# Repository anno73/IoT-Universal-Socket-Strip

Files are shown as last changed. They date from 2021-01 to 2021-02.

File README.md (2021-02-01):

# This is work in progress ...

# IoT Universal Socket Strip

Ever wanted to have a customizable socket strip? Now you can... 
This project enhances an [Ehmann](https://www.ehmann-gmbh.de/en/) [Universal Socket Strip](https://www.ehmann-gmbh.de/en/produkte/steckdosensysteme/steckdosenleisten/) 
like the [8-fold strip 0200x00082301](https://www.ehmann-gmbh.de/wp-content/uploads/2017/01/0200x00082301_0200x00082303_0200x00082305-data-sheet.pdf)
with custom relay controller and dedicated switching PCBs for each of the sockets.

The controller PCB is ESP8266 based, ideal for integration into your home IoT installation via e.g. MQTT.

# ToDo

Write firmware

Design power/controller and relay board.

Hardware, Software, Controller PCB, Relay PCB, Supporting Documents

# Best Practice Tutorials

## Git
[Using .gitignore the Right Way](https://labs.consol.de/development/git/2017/02/22/gitignore.html)

https://www.xspdf.com/resolution/57309756.html

## KiCad
[Better manage KiCAD projects using Git](https://medium.com/inventhub/better-manage-kicad-projects-using-git-8d06e1310af8)

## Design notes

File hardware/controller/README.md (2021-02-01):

# Power and Controller Board

ESP8266 - ESP12-F

Split logic from PSU?

AC-DC converter 240V->24V
AC-DC converter 240V->5V
DC-DC 5V 3.3V

Common reset
Level Shifter for IIC

## IIC

### IIC Level shifter

Bidirectional [Level shifting techniques in I2C-bus design](https://www.nxp.com/docs/en/application-note/AN10441.pdf) for Fast-mode and Standard-mode busses

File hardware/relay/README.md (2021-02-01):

# Relay Module PCB

One module for each socket.

# Next board revision

As of (AN2519)[http://ww1.microchip.com/downloads/en/Appnotes/AN2519-AVR-Microcontroller-Hardware-Design-Considerations-00002519B.pdf]

Add pull up resistor to RESET-Vcc (>10k)

Add cap between RESET-GND (100nF) - only if not using DebugWIRE

? Add diode between RESET-Vcc

V Add resistor between RESET-External_RESET_header

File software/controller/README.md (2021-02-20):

# Controller Board Software

ESP8266

[PlatformIO](https://platformio.org)

[VS Code](https://code.visualstudio.com/)

[IotWebConf](https://github.com/prampec/IotWebConf)

[MQTT](https://github.com/256dpi/arduino-mqtt)

[ArduinoJSON](https://arduinojson.org/)

[I2C - Wire.h](https://github.com/esp8266/Arduino/tree/master/libraries/Wire)

NTP - ESP8266 native

PolledTimeout - ESP8266 native ([Example](https://github.com/esp8266/Arduino/blob/master/libraries/esp8266/examples/BlinkPolledTimeout/BlinkPolledTimeout.ino))

AJAX?

# Supporting Stuff

## Arduino related

## Arduino ESP8266 Core related

[ESP8266 Blink with polledTimeout by Daniel Salazar](https://github.com/esp8266/Arduino/blob/master/libraries/esp8266/examples/BlinkPolledTimeout/BlinkPolledTimeout.ino) instead of millis() workaround.

## Exception Stack Trace Decoder

https://github.com/me-no-dev/EspExceptionDecoder

## I2C 

### Wire library

I encountered persisting problems with reading data from relay board. What solved it in the end was to add Wire.setClockStretchLimit() after Wire.begin():
```
Wire.begin(PIN_SDA, PIN_SCL, 1);  // Init IIC with master address 1
Wire.setClock(100000);            // 100kHz clock speed
Wire.setClockStretchLimit(40000); // 40ms
```

### I2C Level shifter

?? Use I2C against 5V rail? ESP8266 is 5V tolerant.

As it seems, a 5V powered ATTiny85 does not recognize 3.3V levels on I2C. So a level shifter needs to be used to convert to 5V levels as used by the ATTiny.

[sparkfun - Bi-Directional Logic Level Converter Hookup Guide](https://learn.sparkfun.com/tutorials/bi-directional-logic-level-converter-hookup-guide/all)

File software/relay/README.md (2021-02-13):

# Relay Board Software 

[ATTiny85](https://www.microchip.com/wwwproducts/en/ATtiny85)

[PlatformIO](https://platformio.org)

[VS Code](https://code.visualstudio.com/)

[I2C TinyWireSIO](https://github.com/rambo/TinyWire)

[EEPROMWearLevel](https://github.com/PRosenb/EEPROMWearLevel)

[SendOnlySoftwareSerial](https://github.com/nickgammon/SendOnlySoftwareSerial)

[Streaming](https://github.com/janelia-arduino/Streaming)

[avr-libc Watchdog](https://www.nongnu.org/avr-libc/user-manual/group__avr__watchdog.html)

Does each device need to remember configuration or should it get updated by host on power up?

# ToDo

- [ ] Sleep when not active - how to wake up? Pin change interrupt? 
- [ ] Watchdog timer
- [ ] Find issue on get requests with interleaving messages / subsequent writes

# Supporting Stuff

## Digistump Digispark USB Dev

### Platformio tweaks

#### Switch the platform package

I have encountered some issues with the Digistump avr package. There is missing EEPROM.h library. To resolve this I copied the original library from the arduino avr package to .platformio/packages/framework-avr-digistump/libraries package.
There is also a lot of unnecessary noise during compilation because of moved header file locations, redefinition of #define BIN and other stuff.
In addition EEPROMWearLevel library did not compile. 
This was the final reason for me to try a different core package.
In the end I overwrote core and variant from [Digispark USB](https://docs.platformio.org/en/latest/boards/atmelavr/digispark-tiny.html#board-atmelavr-digispark-tiny) package to tiny and tinyx5 as it is used by the [generic ATTiny85](https://docs.platformio.org/en/latest/boards/atmelavr/attiny85.html#board-atmelavr-attiny85) definitions (see [attiny85.json](https://github.com/platformio/platform-atmelavr/blob/master/boards/attiny85.json)). Keeping the rest as it is, allowed me to program regularly via USB. See [platformio.ini](platformio.ini).

There is a new actively maintained ATTiny85 core available on https://github.com/ArminJo/DigistumpArduino which gives smaller code, has active development, and more stock libraries. I use this now for further development.

#### Include (missing) libs as submodules

As I did not find [SendOnlySoftwareSerial](https://github.com/nickgammon/SendOnlySoftwareSerial) and a current version of [Streaming](https://github.com/janelia-arduino/Streaming) in PlatformIO's library repository, I added these as [git submodules](https://git-scm.com/book/en/v2/Git-Tools-Submodules) in the library folder.
See [github blog](https://github.blog/) for more information on [how to work with submodules](https://github.blog/2016-02-01-working-with-submodules/).
Especially on initial cloning you might need to use `git clone --recursive <project url>`. If you already have cloned the repository and only miss the submodules, `git submodule update --init --recursive` should do the trick.

### Windows Driver Installation

https://github.com/micronucleus/micronucleus/tree/master/windows_driver_installer

Use [zadig](https://zadig.akeo.ie/).

### Initial Flashing

[Connecting and Programming Your Digispark](http://digistump.com/wiki/digispark/tutorials/connecting)

### Flash digiStump Digispark USB dev board

[Digispark USB Development Board](http://digistump.com/products/1) Webshop listing

[Schematic](https://s3.amazonaws.com/digistump-resources/files/97a1bb28_DigisparkSchematic.pdf)

[Micronucleus](https://github.com/micronucleus/micronucleus) Bootloader

## C/C++

[Enumeration declaration](https://en.cppreference.com/w/cpp/language/enum)

## Arduino related

[Arduino Tutorial: Using millis[] Instead of delay[]](https://www.norwegiancreations.com/2017/09/arduino-tutorial-using-millis-instead-of-delay/)

[Arduino Tutorial: Avoiding the Overflow Issue When Using millis[] and micros[]](https://www.norwegiancreations.com/2018/10/arduino-tutorial-avoiding-the-overflow-issue-when-using-millis-and-micros/)

## I2C Resources

[I2C [Inter-Integrated Circuit] Bus Technical Overview and Frequently Asked Questions](https://www.esacademy.com/en/library/technical-articles-and-documents/miscellaneous/i2c-bus.html)

[Nick Gammon - I2C - Two-Wire Peripheral Interface - for Arduino](http://www.gammon.com.au/forum/?id=10896)

https://www.i2c-bus.org/

## Fuse Calc and Fuse Reset

[Engbedded Atmel AVR® Fuse Calculator](https://www.engbedded.com/fusecalc/)

https://www.elektronik-labor.de/Arduino/Fuses.html

TinyCalibrator from below

https://arduinodiy.wordpress.com/2015/05/16/high-voltage-programmingunbricking-for-attiny/

[Simple and Cheap Fuse Doctor for Attiny](https://www.instructables.com/Simple-and-cheap-Fuse-Doctor-for-Attiny/)

## Flash ATTiny85

### High Voltage Programming

[Nick Gammon - High-voltage programming for AVR chips](http://www.gammon.com.au/forum/?id=12898)

https://github.com/ArminJo/ATtiny-HighVoltageProgrammer_FuseEraser

### Flash ATTiny85

Arduino as a programmer

### Boot loader

[ATtiny85 I2C Bootloader](https://github.com/casanovg/timonel) to flash via ESP8266.
https://www.youtube.com/watch?v=-7GOMToGvzI

[Micronucleus](https://github.com/micronucleus/micronucleus) V-USB based.

## Debugging

### Serial TX only

https://github.com/nickgammon/SendOnlySoftwareSerial

### debugWire

* https://sites.google.com/site/wayneholder/debugwire
* https://www.youtube.com/watch?v=kI_Z78a_0y0

### IIC

[SoftI2CMaster](https://github.com/felias-fogg/SoftI2CMaster) provides [I2CShell](https://github.com/felias-fogg/SoftI2CMaster/tree/master/examples/I2CShell) as an example, which is a nice I2C command sending tool for Arduino.

## Calibrate RC Oscillator

* http://ww1.microchip.com/downloads/en/appnotes/atmel-2555-internal-rc-oscillator-calibration-for-tinyavr-and-megaavr-devices_applicationnote_avr053.pdf
* https://hackaday.com/2020/12/30/improve-attiny-timing-accuracy-with-this-clock-calibrator/
* https://hackaday.io/project/176542-tiny-calibrator
* https://github.com/wagiminator/ATtiny84-TinyCalibrator

## Power saving mode

[ATTiny85 Data sheet](https://ww1.microchip.com/downloads/en/DeviceDoc/Atmel-2586-AVR-8-bit-Microcontroller-ATtiny25-ATtiny45-ATtiny85_Datasheet.pdf) chapters
* 7 Power Management and Sleep Modes
* Table 7-1 Active Clock Domains and Wake-up Sources in the Different Sleep Modes
* 15.3.4 Two-wire Mode
* 15.3.5 Start Condition Detector
* 15.5.3 Bit 7 USISIF describes conditions for IIC Start condition waking up the CPU from sleep states.

Minimal power consumption is not required to not interfere with peripherals like LED and relay triggering outputs.

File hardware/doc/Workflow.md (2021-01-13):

# Used tools
* python
* freerouter
* KiKit

# Draw schematic in KiCad
# Create PCB
## Draw outlines
## Import components from schematic
## Place components
## Export Specctra DSN
 
# Autoroute
 
## Start Tools_Freerouter.cmd

# Reimport SES file to KiCad

# Panelize/Render/Document KiKit
## Setup Makefile

KiKit [panelization options explained](https://github.com/yaqwsx/KiKit/blob/master/doc/examples.md).

## Start Tools_KiKit.cmd (one off) or Tools_KiKit_Shell.cmd (repeat)

# To Do

* Export schematic to PDF
* Export PCB to PDF
* Export PCB to PNG

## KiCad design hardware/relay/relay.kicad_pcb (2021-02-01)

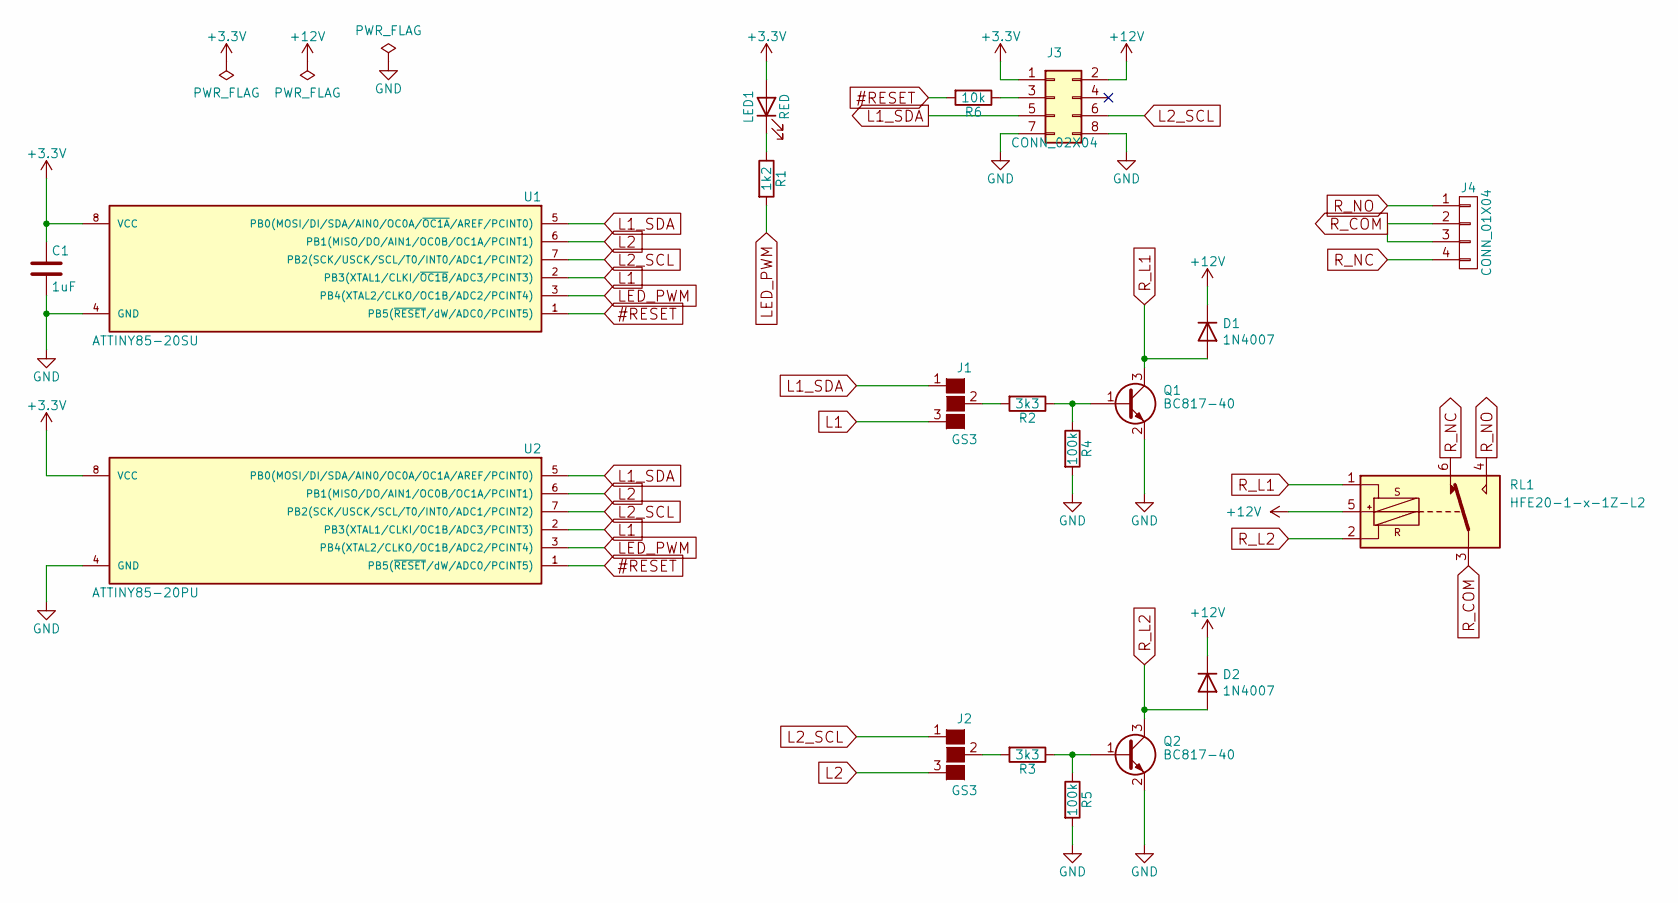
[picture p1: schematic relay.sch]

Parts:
C1: 1uF; C_0805_HandSoldering
D1, D2: 1N4007; D_SMA_Handsoldering
J1, J2: GS3
J3: CONN_02X04; Pin_Header_Straight_2x04_Pitch2.54mm
J4: CONN_01X04; SR21504VBNC
LED1: RED; LED_0805_HandSoldering
Q1, Q2: BC817-40; SOT-23_Handsoldering
R1: 1k2; R_0805_HandSoldering
R2, R3: 3k3; R_0805_HandSoldering
R4, R5: 100k; R_0805_HandSoldering
R6: 10k; R_0805_HandSoldering
RL1: HFE20-1-x-1Z-L2; HFE20-1_DPST_Double_Coil_Bistable
U1: ATTINY85-20SU; SOIC-8_3.9x4.9mm_Pitch1.27mm
U2: ATTINY85-20PU; DIP-8_W7.62mm_Socket

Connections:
#RESET: R6.2, U1.1 (PB5(~RESET~/dW/ADC0/PCINT5)), U2.1 (PB5(~RESET~/dW/ADC0/PCINT5))
+3V3: C1.1, J3.1, LED1.2 (A), U1.8 (VCC), U2.8 (VCC)
+12V: D1.1 (K), D2.1 (K), J3.2, RL1.5
GND: C1.2, J3.7, J3.8, Q1.2 (E), Q2.2 (E), R4.2, R5.2, U1.4 (GND), U2.4 (GND)
L1: J1.3 (G3), U1.2 (PB3(XTAL1/CLKI/~OC1B~/ADC3/PCINT3)), U2.2 (PB3(XTAL1/CLKI/OC1B/ADC3/PCINT3))
L1_SDA: J1.1 (G1), J3.5, U1.5 (PB0(MOSI/DI/SDA/AIN0/OC0A/~OC1A~/AREF/P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), U2.5 (PB0(MOSI/DI/SDA/AIN0/OC0A/OC1A/AREF/PCI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)
L2: J2.3 (G3), U1.6 (PB1(MISO/DO/AIN1/OC0B/OC1A/PCINT1)), U2.6 (PB1(MISO/DO/AIN1/OC0B/OC1A/PCINT1))
L2_SCL: J2.1 (G1), J3.6, U1.7 (PB2(SCK/USCK/SCL/T0/INT0/ADC1/PCINT2)), U2.7 (PB2(SCK/USCK/SCL/T0/INT0/ADC1/PCINT2))
LED_PWM: R1.2, U1.3 (PB4(XTAL2/CLKO/OC1B/ADC2/PCINT4)), U2.3 (PB4(XTAL2/CLKO/OC1B/ADC2/PCINT4))
unnamed: J1.2 (G2), R2.2
unnamed: J2.2 (G2), R3.2
unnamed: J3.3, R6.1
unnamed: LED1.1 (K), R1.1
unnamed: Q1.1 (B), R2.1, R4.1
unnamed: Q2.1 (B), R3.1, R5.1
R_COM: J4.2, J4.3, RL1.3
R_L1: D1.2 (A), Q1.3 (C), RL1.1
R_L2: D2.2 (A), Q2.3 (C), RL1.2
R_NC: J4.4, RL1.6
R_NO: J4.1, RL1.4

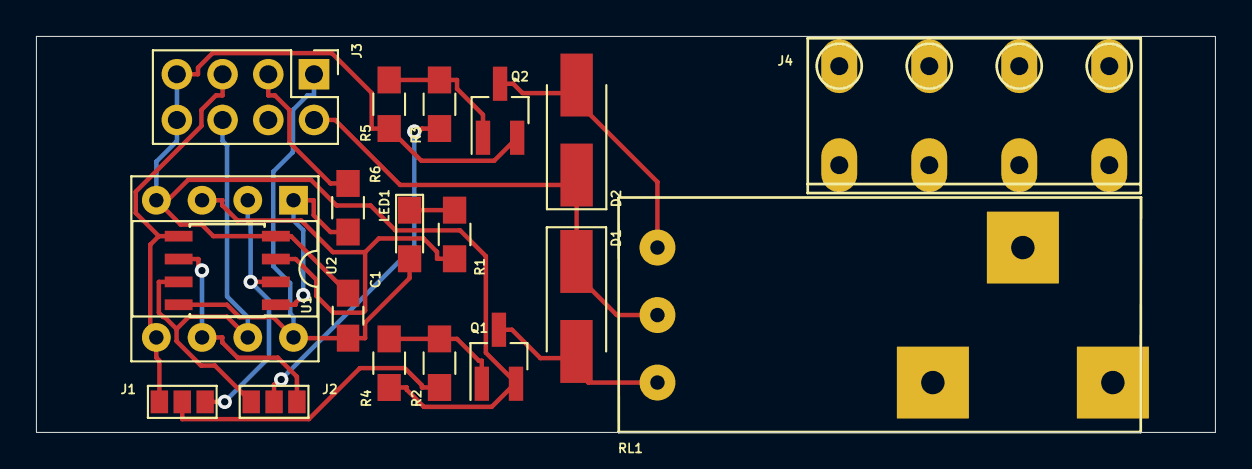
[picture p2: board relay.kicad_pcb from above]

Board: 2 copper layers, 65.5 x 22.0 mm, 19 parts (0 on the bottom side), 20 nets.

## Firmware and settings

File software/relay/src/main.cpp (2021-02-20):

#include <Arduino.h>

// #include <avr/sleep.h>
// #include <avr/power.h>

#include "shared.h"

#define DEBUG_IIC_IO
#define DEBUG_CMD
#define DEBUG_CONFIG
// #define DEBUG_EEPROM

#ifdef DEBUG_EEPROM
#define DEBUG_CORE
#define dbg_eep(x) txOnlySerial << x
#else
#define dbg_eep(x)
#endif

#ifdef DEBUG_IIC_IO
#define DEBUG_CORE
#define dbg_iic_io(x) txOnlySerial << x
#else
#define dbg_iic_io(x)
#endif

#ifdef DEBUG_CMD
#define DEBUG_CORE
#define dbg_cmd(x) txOnlySerial << x
#else
#define dbg_cmd(x)
#endif

#ifdef DEBUG_CONFIG
#define DEBUG_CORE
#define dbg_cfg(x) txOnlySerial << x
#else
#define dbg_cfg(x)
#endif

#ifdef DEBUG_CORE
#warning DEBUG enabled on target. SoftwareSerial output on LED pin.
const unsigned long txOnlySerialBaudRate = 115200;
#include <SendOnlySoftwareSerial.h> // https://github.com/nickgammon/SendOnlySoftwareSerial
#include <Streaming.h>              // https://github.com/janelia-arduino/Streaming
// #define dbg(x) txOnlySerial << x
#define dbg_core(x) txOnlySerial << x
#else
// #define dbg(x)
#define dbg_core(x)
#endif

#include "EEPROM.h"
#include <EEPROMWearLevel.h> // https://github.com/PRosenb/EEPROMWearLevel

// const byte EWL_LAYOUT_VERSION = 1;
#define EWL_LAYOUT_VERSION 1
// const int EWL_USE_BYTES = 500;
#define EWL_USE_BYTES 500

const int EWLIDX_STATUS = 0;
const int EWLIDX_RELAY = 1;
const int EWLIDX_LED = 2;
// const int EWLIDX_BUTTON = 3;
// const int EWLIDX_COUNT = 3;
#define EWLIDX_COUNT 3

const unsigned int EEPIDX_IICADDR = 511; // Absolute EEPROM index

#include <TinyWireS.h> // https://github.com/nickcengel/TinyWireSio
#ifndef TWI_RX_BUFFER_SIZE
#define TWI_RX_BUFFER_SIZE (16)
#endif

#define CIRCULAR_BUFFER_INT_SAFE
#include <CircularBuffer.h> // https://github.com/rlogiacco/CircularBuffer

CircularBuffer<uint8_t, TWI_RX_BUFFER_SIZE> cmdBuf; // Command buffer for processing IIC commands in main loop.

#include <avr/wdt.h> // avr-libc watchdog library https://www.nongnu.org/avr-libc/user-manual/group__avr__watchdog.html <Watchdog.h> does not support ATTiny85

/**
 * Forward Declarations
 */
void initIic(uint8_t);
void iicRequestEventCb(void);
void iicReceiveEventCb(uint8_t);
void dumpEEPROM(void);

/**
 * ATTiny85 Pin Usage
 * 
 * ATTiny   Port  Arduino   Function
 * Pin #    Pin   Pin # 
 *   1      PB5    5/A0     /RESET
 *   2      PB3    3/A3
 *   3      PB4    4/A2
 *   4      -       -       GND
 *   5      PB0     0       IIC SDA
 *   6      PB1     1
 *   7      PB2    2/A1     IIC SCL
 *   8              -       VCC
 */

const uint8_t PIN_SCL = 0;
const uint8_t PIN_SDA = 2;

const uint8_t PIN_RL1 = 1;
const uint8_t PIN_RL2 = 3;

const uint8_t PIN_LED = 4;
const uint8_t PIN_BUTTON = 5;

const uint32_t IIC_BITRATE = 100000;
volatile uint8_t iicSlaveAddress = 127; // "Factory" default address for automated recognition of new modules and initialisation by controller
// volatile uint8_t iicSlaveAddress = 125; // Test address during dev
uint8_t softwareVersion = 0;

// const uint8_t RELAY_SWITCH_PULSE_DURATION_MS = 15;
const uint8_t RELAY_SWITCH_PULSE_DURATION_MS = 50;
// const uint8_t RELAY_COIL_OFF = LOW;
// const uint8_t RELAY_COIL_ON = HIGH;
const uint8_t RELAY_COIL_OFF = HIGH;
const uint8_t RELAY_COIL_ON = LOW;

const uint8_t LED_ON = LOW;
const uint8_t LED_OFF = HIGH;

#ifdef DEBUG_CORE
SendOnlySoftwareSerial txOnlySerial(PIN_LED); // Reuse LED pin for software serial.
#endif

/*
  Operations !!! BEWARE OF FEATURE CREEP !!! Maybe creep a bit for education and fun.

  Button is totally optional due to mechanical reasons of base hardware.

  Relay operation
    Set relay state ON/OFF
    Get relay state
    Set freeze relay state lock/unlock 
    Get freeze relay state
  Set LED operational mode
    0: Follow relay (default)
    1: -
    2: Independent fixed state
      0: off
      1: on
    4: Independent blink
      3..0: rate
  Get LED status
  Get LED operational mode
  Set button operation
    0: Toggle relay
    1: off
    2: notify I2C master
  Get button status
  Set IIC Address
  Get IIC Address
  Get Software Version
*/

/**
 * 
 * ??? have array or dedicated variables to hold I2C register values
 * ??? we could have "virtual" registers not needing a storage space because they trigger some action upon r/w.
 *
 * Usage would probably be like this then:
 * typedef struct { uint8_t a, b, c; } reg_struct; 
 * union iicReg_u { uint8_t r[6] ; reg_struct s; }
 * iicReg_u iicRegs;
 * iicReg.r[0] = 0;
 * iicReg.s.a = 0;
 * 
 */

// Make this a union of array and struct
// volatile uint8_t iicRegs[] = {
//     0x00, // 0: Status Register
//     0x00, // 1: Set relay state
//     0x00, // 2: IIC Address Register
//     0x00  // 3: Software version
// };

// For now be conservative and define each possible register on its own. Select access via switch/case instead of array index.

/**
 * statusReg
 * 
 * 76543210
 * 
 * 0: relay status
 *      0: off
 *      1: on
 * 2: led status
 *      0: off
 *      1: on
 * 7: busy - cannot accept command
 *      0: false - commands accepted
 *      1: true - commands accepted but discarded
 */
volatile uint8_t statusReg = 0;
const uint8_t STATUS_BIT_RELAY = 0;
const uint8_t STATUS_BIT_LED = 2;
const uint8_t STATUS_BIT_BUSY = 7;

/**
 * relayReg
 * 
 * 76543210
 * 
 * 0:   on/off
 *      0: relay off
 *      1: relay on
 * 1:   freeze/unfreeze
 *      0: unfreeze
 *      1: freeze
 */
volatile uint8_t relayReg = 0;
const uint8_t RELAY_BIT_ONOFF = 0;
const uint8_t RELAY_BIT_FREEZE = 1;

/**
 * ledReg
 * 
 * 76543210
 * 
 * 0: on/off
 *      0: off
 *      1: on
 * 1:   follow relay
 *      0: follow relay
 *      1: switch separately
 * 2:   freeze/unfreeze
 *      0: unfreeze
 *      1: freeze
 * 3:
 * 54:  blink rate
 *      00
 *      01
 *      10
 *      11
 */
volatile uint8_t ledReg = 0;
const uint8_t LED_BIT_ONOFF = 0;
const uint8_t LED_BIT_FOLLOW = 1;
const uint8_t LED_BIT_FREEZE = 2;

/**
 * buttonReg
 * 
 * 76543210
 * 
 * 0: on/off    Read only
 *      0: off
 *      1: on
 * 1: enable/disable
 *      0: enabled
 *      1: disabled
 * 2: freeze/unfreeze
 *      0: unfreeze
 *      1: freeze
 */
volatile uint8_t buttonReg = 0;
// volatile uint8_t addrReg = 0;    // does not need to be a physical register. Is obtained from EEPROM.
// volatile uint8_t versionReg = 0; // does not need to be a physical register. Is a constant in the code.

volatile uint8_t iicRegSelectedRead = 0;          // For read operations persist the selected register across IIC operations
const uint8_t iicRegSize = iicRegister::REGCOUNT; // How many registers we have defined
const uint8_t iicRegLastIdx = iicRegSize - 1;     // Index of the last register for wrap around on multiple read/write operations
                                                  //
volatile bool persistIicRegs = false;             // If true, persist register values in main loop

/**
 * ledAction
 * 
 * Execute actions/configs on LED
 *  ON/OFF/TOGGLE/...
 * 
 */
void ledAction(uint8_t action)
{

    // dbg_core(F("ledAction: ") << action << endl);
    dbg_core(millis() << F(" ledAction: ") << action << endl);

    if (bitRead(ledReg, LED_BIT_FOLLOW) == 0)
    { // LED in follow relay mode. Only some actions allowed:
        switch (action)
        {
        case ledCmd::UNFOLLOW_RELAY: // intentionally fallthrough all allowed commands.
        case ledCmd::FOLLOW_RELAY:
        case ledCmd::FREEZE:
        case ledCmd::UNFREEZE:
        case ledCmd::RELAY_OFF:
        case ledCmd::RELAY_ON:
            break;
        default:
            return;
        }
    }

    if (bitRead(ledReg, LED_BIT_FREEZE) == 1)
    { // LED in freeze mode. Only some actions allowed:
        switch (action)
        {
        case ledCmd::RELAY_OFF: // intentionally fallthrough all allowed commands.
        case ledCmd::RELAY_ON:
        case ledCmd::FREEZE:
        case ledCmd::UNFREEZE:
            break;
        default:
            return;
        }
    }

    persistIicRegs = true;

    switch (action)
    {
    case ledCmd::RELAY_OFF:
        bitClear(ledReg, LED_BIT_ONOFF);
        bitClear(statusReg, STATUS_BIT_LED);

#ifndef DEBUG_CORE
        // In debug mode PIN_LED gets serial output
        digitalWrite(PIN_LED, LED_OFF);
#endif
        break;
    case ledCmd::RELAY_ON:
        bitSet(ledReg, LED_BIT_ONOFF);
        bitSet(statusReg, STATUS_BIT_LED);

#ifndef DEBUG_CORE
        // In debug mode PIN_LED gets serial output
        digitalWrite(PIN_LED, LED_ON);
#endif
        break;
    case ledCmd::UNFOLLOW_RELAY:
        bitClear(ledReg, LED_BIT_FOLLOW);
        break;
    case ledCmd::FOLLOW_RELAY:
        bitSet(ledReg, LED_BIT_FOLLOW);

        // Initialize LED with current relay state
        if (bitRead(relayReg, RELAY_BIT_ONOFF) == 0)
        {
            ledAction(ledCmd::RELAY_OFF);
        }
        else
        {
            ledAction(ledCmd::RELAY_ON);
        }
        break;
    case ledCmd::OFF:
        bitClear(ledReg, LED_BIT_ONOFF);
        bitClear(statusReg, STATUS_BIT_LED);

#ifndef DEBUG_CORE
        // In debug mode PIN_LED gets serial output
        digitalWrite(PIN_LED, LED_OFF);
#endif
        break;
    case ledCmd::ON:
        bitSet(ledReg, LED_BIT_ONOFF);
        bitSet(statusReg, STATUS_BIT_LED);

#ifndef DEBUG_CORE
        // In debug mode PIN_LED gets serial output
        digitalWrite(PIN_LED, LED_ON);
#endif
        break;
    case ledCmd::TOGGLE:
        if (bitRead(ledReg, LED_BIT_ONOFF) == 0)
        {
            ledAction(ledCmd::ON);
        }
        else
        {
            ledAction(ledCmd::OFF);
        }
        break;
    case ledCmd::UNFREEZE:
        bitClear(ledReg, LED_BIT_FREEZE);
        break;
    case ledCmd::FREEZE:
        bitSet(ledReg, LED_BIT_FREEZE);
        break;
    default:
        // Unknown or unimplemented command
        persistIicRegs = false;
        break;
    }

    return;
} // ledAction

/**
 * relayAction
 * 
 * Initial idea:
 * Execute operations that take longer than allowed in the IIC callback routine.
 * This is mainly the relay switching, as it requires some delay on the coil to properly switch.
 * 
 * Now:
 * Encapsulate relay operation
 */
void relayAction(uint8_t action)
{

    // dbg_core(F("relayAction: ") << action << endl);
    dbg_core(millis() << F(" relayAction: ") << action << endl);

    // If relay is in freeze state then only action allowed is unfreeze
    if (bitRead(relayReg, RELAY_BIT_FREEZE) && (action != relayCmd::UNFREEZE))
    {
        return;
    }

    persistIicRegs = true;

    switch (action)
    {
    case relayCmd::OFF:
        // if (bitRead(relayReg, RELAY_BIT_ONOFF) == 0)
        // {
        //     persistIicRegs = false;
        //     break;
        // }
        bitClear(statusReg, STATUS_BIT_RELAY);
        bitClear(relayReg, RELAY_BIT_ONOFF);

        digitalWrite(PIN_RL1, RELAY_COIL_ON);
        tws_delay(RELAY_SWITCH_PULSE_DURATION_MS);
        digitalWrite(PIN_RL1, RELAY_COIL_OFF);

        ledAction(ledCmd::RELAY_OFF);
        break;
    case relayCmd::ON:
        // if (bitRead(relayReg, RELAY_BIT_ONOFF) == 1)
        // {
        //     persistIicRegs = false;
        //     break;
        // }
        bitSet(statusReg, STATUS_BIT_RELAY);
        bitSet(relayReg, RELAY_BIT_ONOFF);

        digitalWrite(PIN_RL2, RELAY_COIL_ON);
        tws_delay(RELAY_SWITCH_PULSE_DURATION_MS);
        digitalWrite(PIN_RL2, RELAY_COIL_OFF);

        ledAction(ledCmd::RELAY_ON);
        break;
    case relayCmd::TOGGLE:
        if (relayReg & 1)
        {
            relayAction(relayCmd::OFF);
        }
        else
        {
            relayAction(relayCmd::ON);
        }
        break;
    case relayCmd::FREEZE:
        bitSet(relayReg, RELAY_BIT_FREEZE);
        break;
    case relayCmd::UNFREEZE:
        bitClear(relayReg, RELAY_BIT_FREEZE);
        break;
    default:
        // Unknown or unimplemented command
        persistIicRegs = false;
        break;
    }

    return;
} // relayAction

/**
 *  iicRequestEventCb
 * 
 * This is called for each read request we receive.
 * Never put more than one byte of data (with TinyWireS.send) to the send-buffer when using this callback.
 * 
 */
void iicRequestEventCb(void)
{

    // dbg_iic_io(F("iicRequestEventCb Reg: ") << iicRegSelectedREad << endl);
    dbg_iic_io(millis() << F(" iicRequestEventCb Reg: ") << iicRegSelectedRead << endl);

    switch (iicRegSelectedRead)
    {
    case iicRegister::STATUS:
        TinyWireS.send(statusReg);
        break;
    case iicRegister::RELAY:
        TinyWireS.send(relayReg);
        break;
    case iicRegister::LED:
        TinyWireS.send(ledReg);
        break;
    case iicRegister::BUTTON:
        TinyWireS.send(buttonReg);
        break;
    case iicRegister::ADDR:
        TinyWireS.send(iicSlaveAddress);
        break;
    case iicRegister::VERSION:
        TinyWireS.send(softwareVersion);
        break;
    default:
        break;
    }

    // Increment the reg position on each read, and loop back to zero
    iicRegSelectedRead++;

    // Treat registers as ring buffer. Check for possible wrap around and handle it.
    if (iicRegSelectedRead >= iicRegLastIdx)
    {
        iicRegSelectedRead = 0;
    }

    // dbg_iic_io(F("iicReqCb: response sent. iicRegSelected: ") << iicRegSelected << endl);
    dbg_iic_io(millis() << F(" iicReqCb: response sent. iicRegSelected: ") << iicRegSelectedRead << endl);

} // iicRequestEventCb

/**
 * 
 * iicReceiveEventCb
 * 
 * The I2C data received handler triggers actions in our little device.
 *
 * This needs to complete before the next incoming transaction (start, data, restart/stop) on the bus does
 * so be quick, set flags for long running tasks to be called from the mainloop instead of running them directly
 * 
 * todo: Ignore IIC request while command still pending.
 * Alternative: ignore any additional write command as long one is still pending. Exception: write new address for reading e.g. STATUS register.
 * Would require to persist data across calls as TinyWireS is not redundant, it has only one data buffer for TinyWireS.receive.
 * 
 */
void iicReceiveEventCb(uint8_t howMany)
{

    // dbg_iic_io(F("iicReceiveEventCb: ") << howMany << F(" bytes") << endl);
    dbg_iic_io(millis() << F(" iicReceiveEventCb: ") << howMany << F(" bytes") << endl);

    if (howMany < 1)
        // Sanity check
        return;

    if (howMany > TWI_RX_BUFFER_SIZE)
        // Sanity check - should no occur really
        return;

    uint8_t iicRegSelected = TinyWireS.receive();

    if (iicRegSelected >= iicRegLastIdx)
    { // Sanity check - non existant register requested
        if (iicRegSelected != iicRegister::REGSPECIAL)
        { // non existant registers get remapped / ignored
            // iicRegSelected = iicRegister::STATUS;
            return;
        }
    }

    howMany--;

    if (!howMany)
    {
        // This write was only to select the register for next read operation (iicRequestEvent)
        iicRegSelectedRead = iicRegSelected;

        dbg_iic_io(F("iicRecCb: Reg: ") << iicRegSelectedRead << F(" for reading") << endl);
        return;
    }

    // Seems we got a valid write request with at least another byte of data
    // iicRegSelected indicates what register to start with as subsequent received bytes advance to the next register

    if (!cmdBuf.isEmpty())
        // Still a pending command to be processed. Ignore this one.
        return;

    // Store register from above to buffer
    cmdBuf.push(iicRegSelected);

    // Copy data to buffer for processing in main loop
    // As IIC buffer size == cmdBuffer size, there cannot be an overrun
    while (howMany--)
    {
        // Store data to buffer
        cmdBuf.push(TinyWireS.receive());
    }

    // Set command in progress flag in staus register
    bitSet(statusReg, STATUS_BIT_BUSY);

    return;
} // iicReceiveEventCb

/**
 * processCommand
 * 
 * Process one command stored in cmdBuf.
 * Buffer cleanup happens by caller.
 * 
 */
void processCommand(void)
{

    if (cmdBuf.isEmpty())
    {
        // Empty buffer, no command to process
        return;
    }

    uint8_t iicRegSelected = cmdBuf.shift();

    // Currently we only have commands with two bytes: [ register, data ]
    if (cmdBuf.isEmpty())
    {
        // No databyte left
        return;
    }

    while (!cmdBuf.isEmpty())
    {
        uint8_t data = cmdBuf.shift();

        dbg_cmd(F("iicRecCb: Reg: ") << iicRegSelected << " Data: " << data << endl);

        switch (iicRegSelected)
        {
            // We only allow operation on one attribute at a time
            // An alternate approach would be to XOR new data with register value and process all commands corresponding to set bits.
            // The long running code really should get moved out of here. Might solve the timing issue in a more elegant way.

        // case iicRegister::STATUS:
        // Ignore writes to STATUS register
        // break;
        case iicRegister::RELAY:

            // asyncAction = NOOP;

            switch (data)
            {
            case relayCmd::OFF: // fallthrough all allowed commands for relay
            case relayCmd::ON:
            case relayCmd::TOGGLE:
                relayAction(data);
                break;
            default:
                break;
            } // switch (data)

            // Store in status register is done externally upon real switch
            // Store in EEPROM is done externally upon real switch
            break;
        case iicRegister::LED:
            // Set LED state
            // 0: OFF, 1: ON, 2: TOGGLE, 3: Follow relay state
            switch (data)
            {
            case ledCmd::FOLLOW_RELAY: // fallthrough all allowed commands for LED
            case ledCmd::UNFOLLOW_RELAY:
            case ledCmd::OFF:
            case ledCmd::ON:
            case ledCmd::TOGGLE:
                ledAction(data);
                break;
            default:
                break;
            }
            // Store in status register
            // Store in EEPROM?
            break;
        case iicRegister::BUTTON:
            // Set button state
            // Store in status register
            // Store in EEPROM?
            break;
        case iicRegister::ADDR:
            // Set new IIC address during first initialization
            // Master calls Initial IIC address and updates to new one
            if (!data || data > 127)
                // Sanity check on new IIC address.
                return;
            // Store in status register
            iicSlaveAddress = data;
            // Store in EEPROM
            EEPROM.write(EEPIDX_IICADDR, iicSlaveAddress);
            // Reinitialize IIC
            initIic(iicSlaveAddress);
            break;
        case iicRegister::VERSION:
            // Ignore writes to VERSION register
            break;
        case iicRegister::REGSPECIAL:
            switch (data)
            {
            case specialCmd::RESTART:
                break;
            case specialCmd::CLR_EEPROM:
                for (unsigned int addr = 0; addr < EEPROM.length(); addr++)
                    EEPROM.write(addr, 0xFF);
                break;
            case specialCmd::CLR_EWL:
                for (unsigned int addr = 0; addr < EWL_USE_BYTES; addr++)
                    EEPROM.write(addr, 0xFF);
                break;
            case specialCmd::CLR_IIC_ADDR:
                EEPROM.write(EEPIDX_IICADDR, 0xFF);
                break;
            default:
                break;
            }
            break;
        default:
            break;
        } // switch (iicRegSelected)

        // Advance to next register in case we got multiple data values.
        // In case of last register roll over to first one again.
        iicRegSelected++;
        if (iicRegSelected >= iicRegSize)
        {
            iicRegSelected = 0;
        }

    } // while (!cmdBuf.isEmpty())

    return;
} // processCommand
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
void loop()
{

    // while (1); // Test watchdog timer

    // set_sleep_mode(SLEEP_MODE_PWR_DOWN);
    // sleep_enable();
    // sleep_mode();
    // sleep_disable();

    // Check in buffer if there was a command received via IIC
    while (!cmdBuf.isEmpty())
    {
        // cmdBuf.shift();
        processCommand();

        // Consolidate persisting into one operation as multiple changes can have happened.
        if (persistIicRegs)
        {
            ewlSaveConfig();
            persistIicRegs = false;

            dumpEEPROM();
        }

        { // Atomic operation - sort of - use block to make it explicit
            noInterrupts();

            // Clear command pending satus bit
            bitClear(statusReg, STATUS_BIT_BUSY);
            // Just in case there are any remnants after processing command, clear the buffer.
            cmdBuf.clear();

            interrupts();
        }
    }
    // wdt_reset(); // reset watchdog timer

    TinyWireS_stop_check();

} // loop

/**
 * dumpEEPROM
 * 
 * Dumps the contents of 
 * Function gets optimized away when DEBUG is not set.
 * 
 */
void dumpEEPROM(void)
{
#ifdef DEBUG_EEPROM

    unsigned int idx = 0;
    uint8_t col = 0;
    const uint8_t MAX_COL = 16;

    dbg_eep(_WIDTHZ(_HEX(idx), 3) << F(" : "));

    for (idx = 0; idx < EEPROM.length(); idx++)
    {
        uint8_t data = EEPROM.read(idx);
        dbg_eep(_WIDTHZ(_HEX(data), 2));
        col++;
        switch (col)
        {
        case 8:
            dbg_eep(F(" : "));
            break;
        case 16:
            dbg_eep(endl);
            col = 0;
            if (idx < EEPROM.length() - MAX_COL)
            {
                dbg_eep(_WIDTHZ(_HEX(idx), 3) << F(" : "));
            }
            break;
        default:
            dbg_eep(" ");
            break;
        }
    }

#endif

} // dumpEEPROM

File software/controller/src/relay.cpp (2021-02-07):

#include <Arduino.h>
#include <Streaming.h>

#include <Wire.h>

#include <PolledTimeout.h>

#include "relay.h"

#include "../../relay/src/shared.h" // Shared data and command structures of relay

namespace relay
{

    /**
     * I2C
     * 
     * Default I2C pins on ESP8266
     * D1   SDA
     * D2   SCL
     * 
     */
    const uint8_t PIN_SDA = D1;
    const uint8_t PIN_SCL = D2;

    const uint8_t MAX_IIC_RETRIES = 5;
    const uint8_t INITIAL_IIC_ADDRESS = 127; // "Factory" default IIC address of an uninitialized relay module
    const uint8_t MAX_RELAY_MODULES = 20;    // Maximum number of supported relay modules. Mainly for sanity reasons on IIC bus scanning.
    const uint8_t MODULE_ADDR_OFFSET = 10;   // Start here with addresses for relay modules

    volatile uint8_t countSockets = 0; // Number of detected relay modules.

    /**
     * sendIicCommand
     * 
     * Send a single IIC command to relay module
     * 
     * 
     */
    uint8_t sendIicCommand(uint8_t address, uint8_t iicReg, int8_t value, uint8_t *status, uint8_t *tries)
    {
        *status = 255;
        *tries = 0;

        do
        {
            Wire.beginTransmission(address);
            Wire.write(iicReg);
            Wire.write(value);
            *status = Wire.endTransmission();

            // Serial << F("Write to address ") << address << F(" Status: ") << *status << F(" Try: ") << *tries << endl;
            if (*status != 0)
            {
                (*tries)++;
                delay(10);
            }
        } while ((*status != 0) && (*tries < MAX_IIC_RETRIES));

        // All went well
        if ((*status) == 0)
            return 0;

        // WARNING: we had to retry the operation
        if ((*tries) < MAX_IIC_RETRIES)
            return 1;

        // ERROR: Operation timed out: status != 0 and tries == MAX_IIC_RETRIES
        return 2;

    } // sendIicCommand

    /**
     * switchRelay
     * 
     */
    void switchRelay(uint8_t addr, uint8_t state)
    {
        // Serial << F("Switch relay ") << relay << F(" to state ") << ((state > 0) ? F("ON") : F("OFF")) << "." << endl;

        uint8_t status;
        uint8_t tries;
        uint32_t now = micros();

        addr += MODULE_ADDR_OFFSET;
        switch (sendIicCommand(addr, iicRegister::RELAY, state, &status, &tries))
        {
        // case 0:
        //     break;
        case 1:
            Serial << F("WARNING: Write to relay ") << addr << F(" Status: ") << status << F(" Try: ") << tries << endl;
            break;
        case 2:
            Serial << F("ERROR: Write to relay ") << addr << F(" Status: ") << status << F(" Try: ") << tries << endl;
            break;
            // default:
            //     break;
        }

        uint32_t diff = micros() - now;
        Serial << "switchRelay: diff " << diff << "us" << endl;

        return;
    } // switchRelay

    /**
     * switchLed
     * 
     */
    void switchLed(uint8_t addr, uint8_t state)
    {
        uint8_t status;
        uint8_t tries;

        addr += MODULE_ADDR_OFFSET;
        switch (sendIicCommand(addr, iicRegister::LED, state, &status, &tries))
        {
        case 1:
            Serial << F("WARNING: Write to led ") << addr << F(" Status: ") << status << F(" Try: ") << tries << endl;
            break;
        case 2:
            Serial << F("ERROR: Write to led ") << addr << F(" Status: ") << status << F(" Try: ") << tries << endl;
            break;
        default:
            break;
        }

        return;
    } // switchLed

    /**
     * getRegister
     * 
     * Read one register/byte from module
     * 
     */
    uint8_t getRegister(uint8_t module, uint8_t regIdx, uint8_t *data)
    {

        uint8_t status = 255;
        uint8_t tries = 0;

        uint8_t addr = module + MODULE_ADDR_OFFSET; // map module index to IIC address

        do
        {
            uint32_t now = micros();
            Wire.beginTransmission(addr); // Select register in module to read
            Wire.write(regIdx);
            status = Wire.endTransmission();
            Serial << F("getRegister: IIC call: ") << micros() - now << "us" << endl;

            if (status != 0)
            {
                tries++;
                delay(10);
            }
        } while ((status != 0) && (tries < MAX_IIC_RETRIES));

        if (tries >= MAX_IIC_RETRIES)
        {
            // there was an error
            return status;
        }

        // delay(1); // necessary?

        status = Wire.requestFrom(addr, (uint8_t)1, (uint8_t) true); // Request one byte from module; 3rd parm: true: send stop, false: send restart

        Serial << F("Wire.requestFrom returned ") << status << endl;

        if (status == 0)
        {
            Serial << F("getRegister: ERROR: did not receive any data") << endl;
            return 0x10;
        }

        // We got some data back
        if (Wire.available() == 1)
        {
            *data = Wire.read();
            return 0;
        }
        else
        {
            // We got more data back as expected
            Serial << F("getRegister: ERROR: expected bytes 1 but got ") << Wire.available() << endl;
            return 0x20;
        }

        return 0xA5;
    } // getRegister

    /**
     * setIicAddress
     * 
     */
    void setIicAddress(uint8_t currentAddr, uint8_t newAddr)
    {
        uint8_t status = 255;
        uint8_t tries = 0;

        switch (sendIicCommand(currentAddr, iicRegister::ADDR, newAddr, &status, &tries))
        {
        case 1:
            Serial << F("WARNING: Write to address ") << currentAddr << F(" Status: ") << status << F(" Try: ") << tries << endl;
            break;
        case 2:
            Serial << F("ERROR: Write to address ") << currentAddr << F(" Status: ") << status << F(" Try: ") << tries << endl;
            break;
        default:
            break;
        }

        return;
    } // setIicAddress

    /**
     * getModule
     * 
     * Read registers from relay module
     * 
     * 
     */
    uint8_t getModule(uint8_t idx, uint8_t *status, uint8_t *relay, uint8_t *led, uint8_t *addr, uint8_t *swVers)
    {
        // uint8_t response[5];
        // uint8_t res = 0;

        // if (idx > socketCnt) return 100;

        // res = readIicRegs(...);

        return 0;
    } // getModule

    /**
     * probeIicBusAddr
     * 
     * Probe IIC bus on a given address to see if a device is present.
     * 
     */
    uint8_t probeIicBusAddr(uint8_t addr)
    {
        Serial << F("probeIicBusAddr: ") << addr;

        uint8_t status = 255;
        uint8_t retryCount = 0;

        do
        {
            Wire.beginTransmission(addr);
            status = Wire.endTransmission();
            if (status != 0)
            {
                retryCount++;
                delay(10);
            }
        } while (status != 0 && retryCount <= MAX_IIC_RETRIES);

        Serial << F(" Status: ") << status << endl;
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

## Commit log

2021-01-19 Fix relay footprint
    [relay.kicad_pcb]
2021-01-19 sparkfun digiSpark DEV board
2021-01-20 switch to nodemcu, add IOTWC debug
2021-01-20 test delay() vs millis() hack vs PolledTimeout
2021-01-20 Add mqtt commands for relay and led
2021-01-28 Set digispark as dev board
2021-01-28 refactor, fix request of non existing iic register
    [main.cpp]
2021-01-31 Watchdog timer, docu, typos
2021-01-31 map mqtt relay index to iic address
2021-02-01 Give gerbers for PCB fab a less generic name
2021-02-01 Add power flag, convert label to global labels, add R to protect #RESET
    [relay.sch]
2021-02-01 Fix relay footprint, swap relay and 240V terminals, rearange logic components for easier part placement.
    [relay.kicad_pcb]
2021-02-06 Switch to DigistumpArduino for dev board
2021-02-07 Debugging, REGSPECIAL, fix IIC register select
    [main.cpp]
2021-02-07 Read from relay module, fix read timeout
    [relay.cpp]
2021-02-13 docu ESP8266 Wire.setClockStretchLimit
